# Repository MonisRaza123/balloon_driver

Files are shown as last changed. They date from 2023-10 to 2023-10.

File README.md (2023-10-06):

# balloon_driver
LED Balloon Targets is an LED based electronic version of the popular game Shooting Targets. In this game, the player has to shoot at balloon targets using the gun. The LEDs emulate the balloons and a laser gun is used to shoot them. The LED balloons are arranged in a 4 x 3 matrix.
One LED balloon is made of 4 LEDs and an LDR is embedded in the centre. So there is one LDR corresponding to each balloon. The player has to actually aim at the LDR by the laser gun to shoot the LED balloon. All LED balloons are lighted up initially. As soon as laser falls on any LDR, the LEDs of the corresponding balloon turn off. Once all the LED balloons go off, the buzzer is turned on to indicate the same.
Do you have what it takes to be a great shooter? Test your shooting skills using this game. Load the gun, press the trigger and shoot!

Let us first list down the requirements of the proposed project as follows:
- A device to sense the light coming from laser gun.
- An output device to emulate the balloon.
- An output device to indicate that the game is over.
- A microcontroller to do all the processing.
- A supply to power up the whole circuit.

Now we will try to place the above requirements in the six-box model:
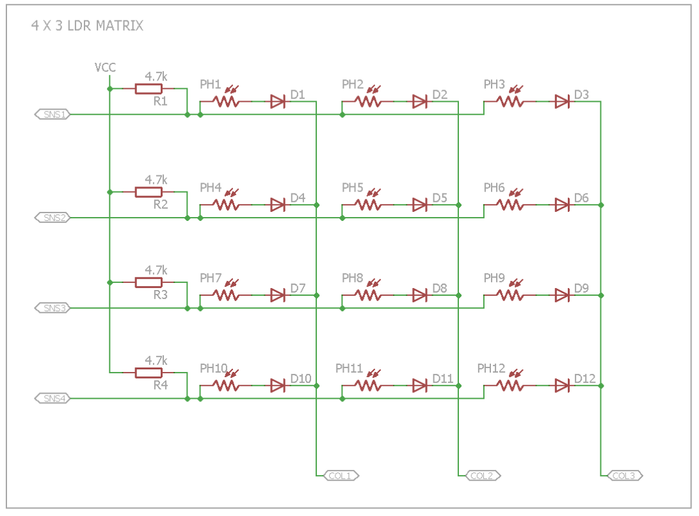
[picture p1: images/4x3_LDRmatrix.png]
1. INPUT: LDR (light-dependent resistor) to detect the change in light when laser falls on it. LDRs are arranged in a 4x3 matrix. 
1. OUTPUTS:
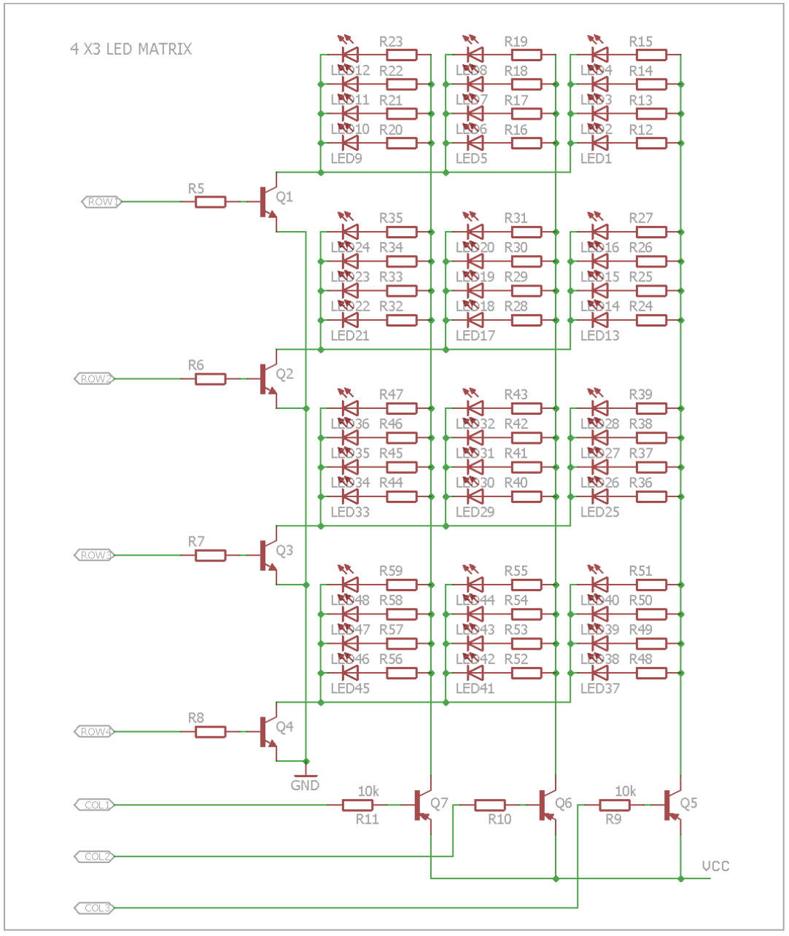
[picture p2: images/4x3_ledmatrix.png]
   1. 4 LEDs to emulate one balloon. Bal- loons are also arranged in a 4x3 matrix. 
   2. Buzzer to indicate that the game is complete i.e. all LED balloons have been shot at.
1. MICROCONTROLLER: The microcontroller used is ESP32 Wroom32.
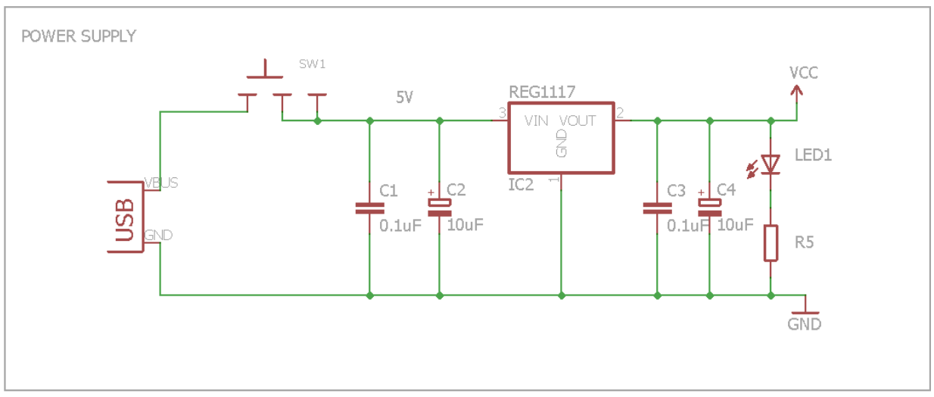
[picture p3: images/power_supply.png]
1. POWER SUPPLY: For keeping the project portable, the power is supplied through a USB Mini B connector, which brings in a raw 5V. This voltage is not suitable to be fed directly to the ESP32. Therefore, LM1117 LDO voltage regulator that gives 3.3V output is used.
1. COMMUNICATION: A 4-pin connector, with Test, Reset, Vcc and GND signals, is provided for downloading code from the emulator. This ensures that the user doesn't have to disconnect the microcontroller from the PCB repeatedly to code it.

## Block Diagram
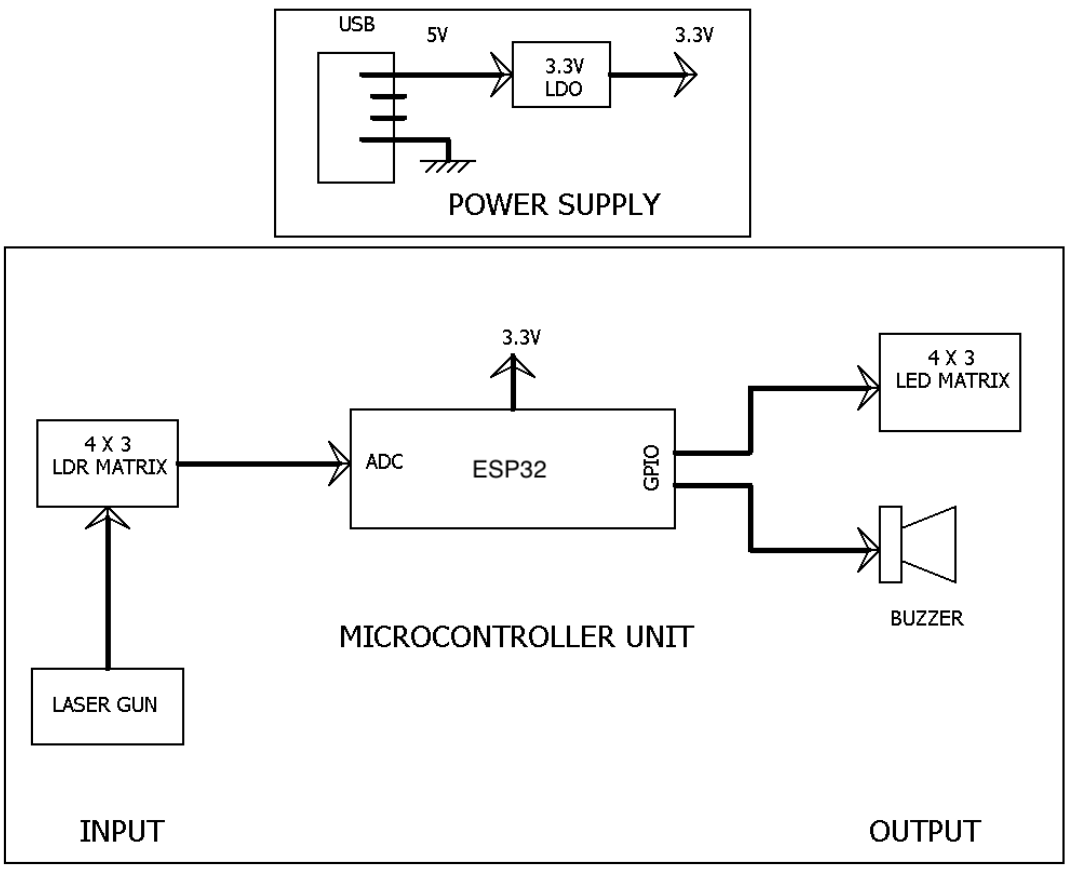
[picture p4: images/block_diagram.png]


## Hardware Description
The hardware of our project comprises of two boards: 
1. Driver circuit board - Consisting of power supply, ESP32 microcontroller, buzzer and connectors.
2. LED Balloon board - Consisting of 4 x 3 LDR matrix and 4 x 3 LED balloon matrix and connectors. The LED Balloon board is stacked above the driver circuit. For this purpose, suitable connectors have been provided.

The working of the project involves the concept of multiplexing. So, before proceeding further one must know how multiplexing works.
- Multiplexing is a technique of driving large number of LEDs using only a few pins of the microcontroller. In multiplexing a set of LEDs are lit for a brief period of time, then the next set is lit, then another set and hence the cycle repeats. This continuous switching ON and OFF of LEDs is done at a rate such that it exceeds the persistence of vision and the human eye perceives all the LEDs to be ON simultaneously.
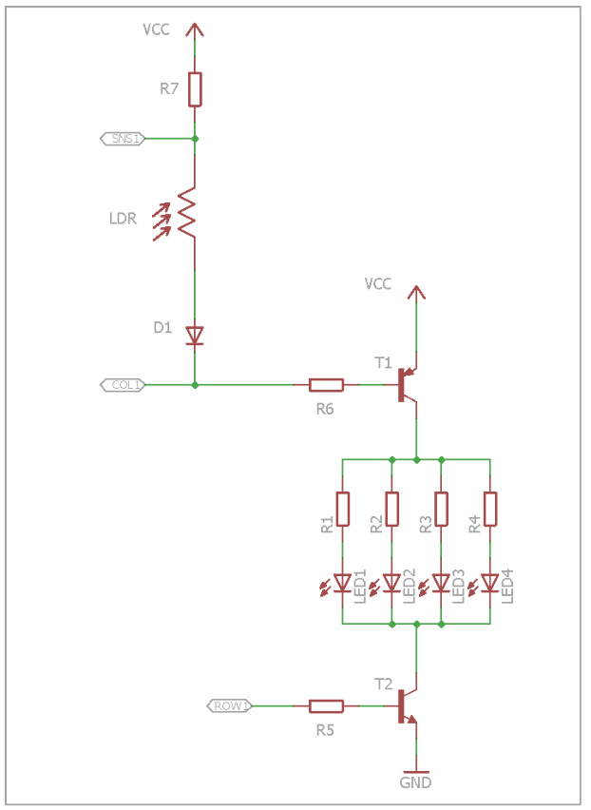
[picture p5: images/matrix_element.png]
- The 4x3 matrix consists of 12 elements. The following circuit corresponds to one element of the matrix:
- Each LED balloon is made up of 4 LEDs which are connected in parallel as shown.
- An NPN transistor, BC547, has been used for low-side switching. It provides the necessary current sinking capabilities required to drive the LEDs.
- A PNP transistor, BC557, has been used for high-side switching. It provides the necessary current sourcing capabilities required to drive the LEDs.
- The SNS1 pin reads the voltage at that point using ADC. When laser light falls on the LDR, its resistance decreases, current through it increases and voltage at SNS1 pin decreases.
- So, if the voltage value at SNS1 pin is above a certain threshold value then ROW1 pin is made high, while COL1 pin is kept low. Hence all the 4 LEDs that make up one balloon light up.
- If the voltage value at SNS1 pin is below a certain threshold value then ROW1 pin is made low, while COL1 pin is kept low. Hence all the 4 LEDs that make up one balloon turn off.
- We deal with only one column at a time. Initially, first column is activated by keeping COL1 low, COL2 and COL3 are kept high, then SNS1, SNS2, SNS3, SNS4 pins are read for the four rows and the corresponding ROW pin is made high or low accordingly. Same procedure is repeated for second and third column too.

## Flowchart
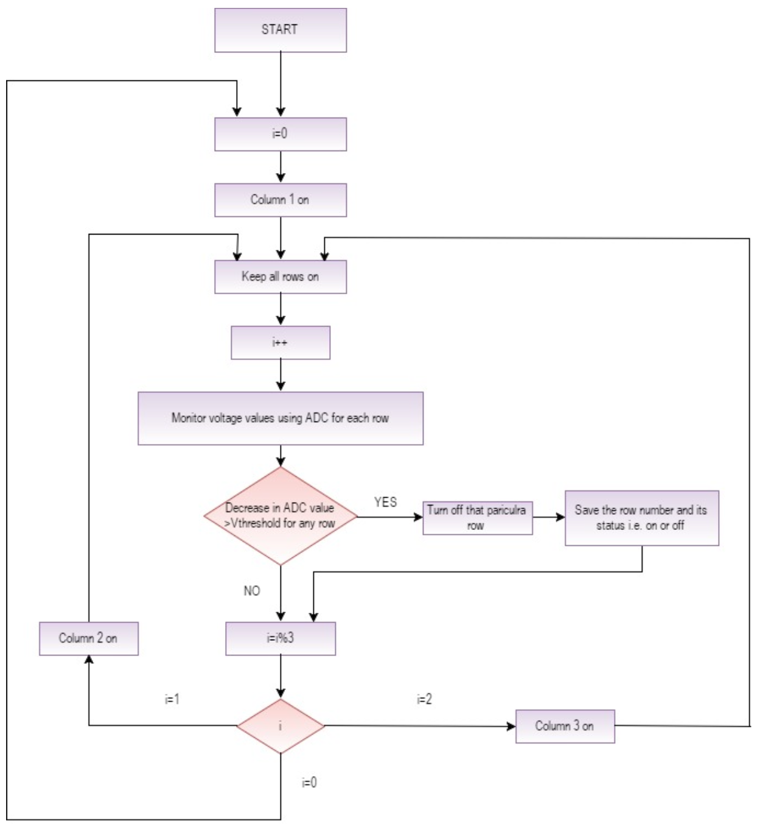
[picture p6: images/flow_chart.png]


## Circuit Design
### Driver Circuit
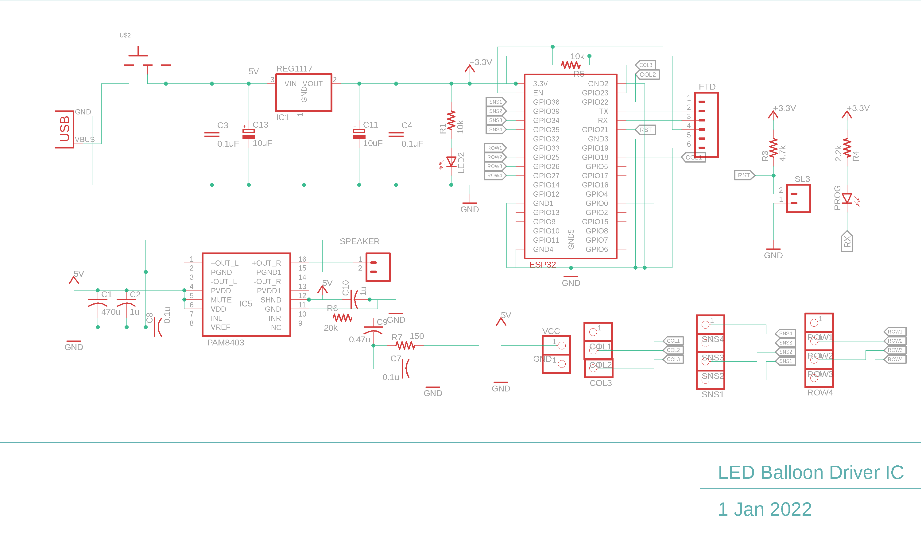
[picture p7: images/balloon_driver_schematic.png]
||
|:--:|
|*Driver board schematic*|

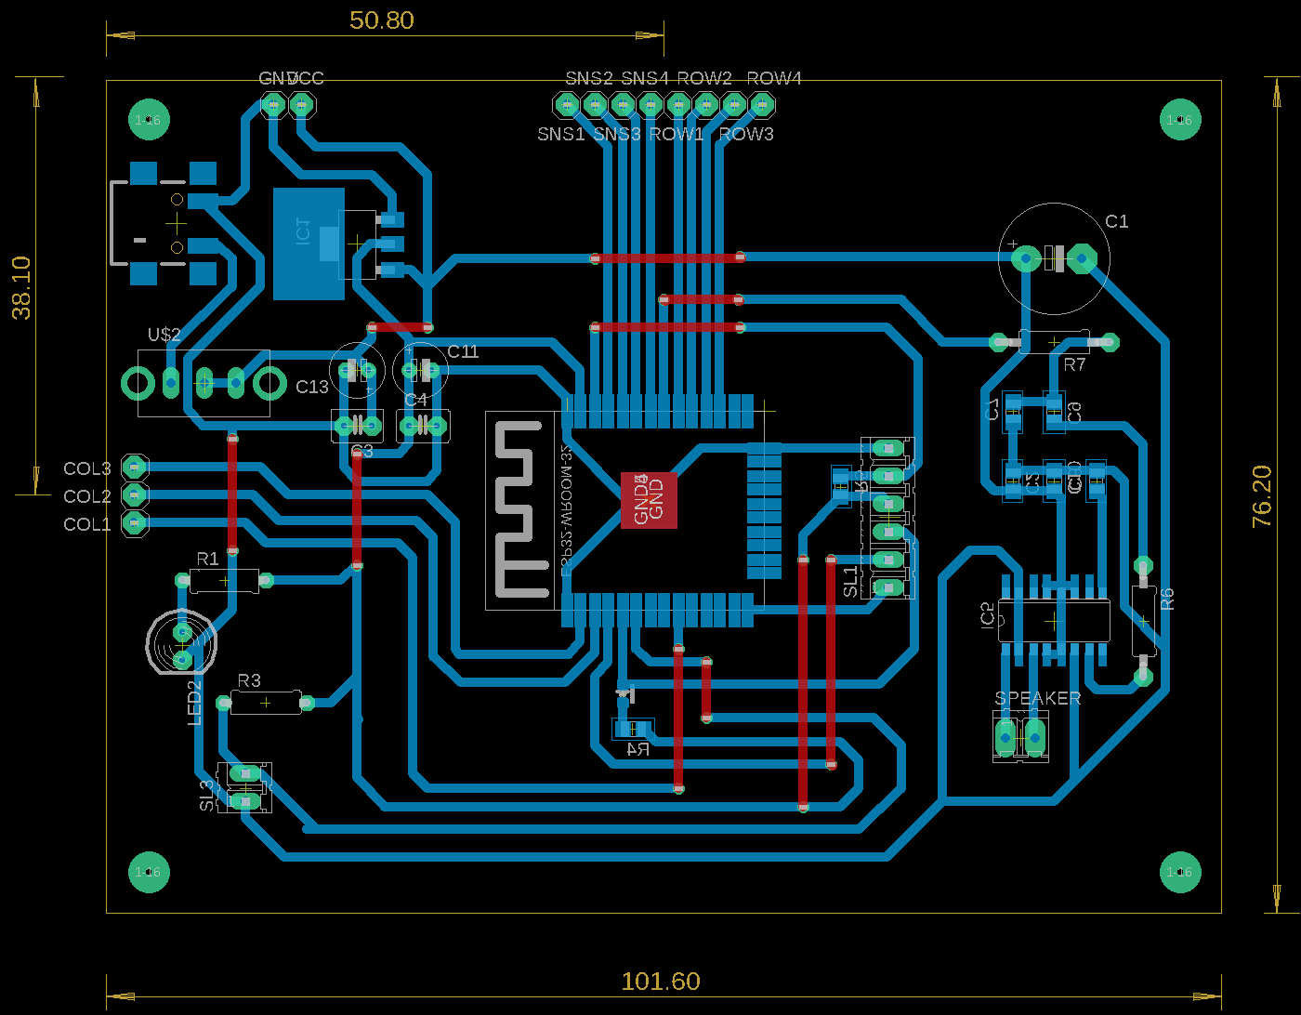
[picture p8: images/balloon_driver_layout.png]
||
|:--:|
|*Driver board layout*|

### LED Balloon Circuit
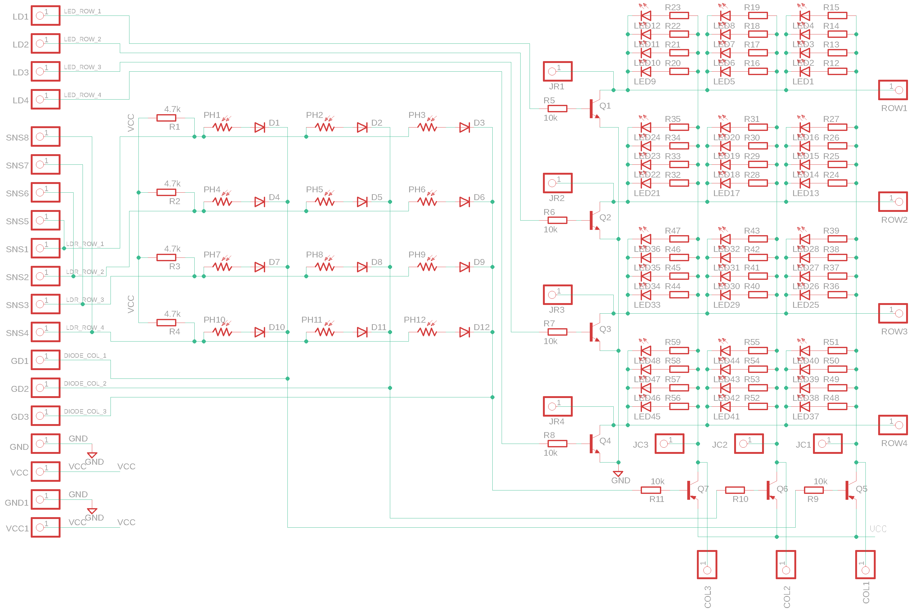
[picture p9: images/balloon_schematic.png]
||
|:--:|
|*Balloon board schematic*|

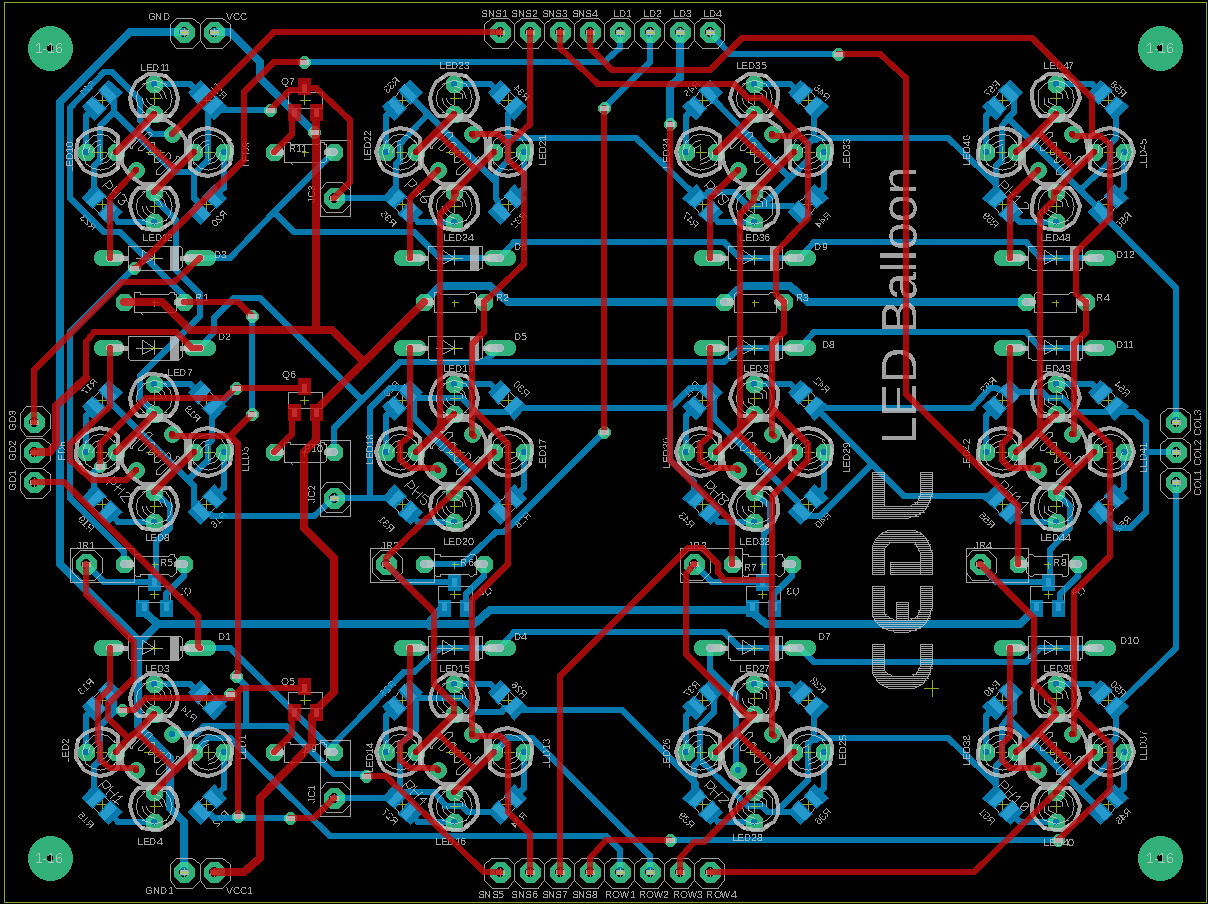
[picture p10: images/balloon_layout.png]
||
|:--:|
|*Balloon board layout*|

## Fabricated PCB
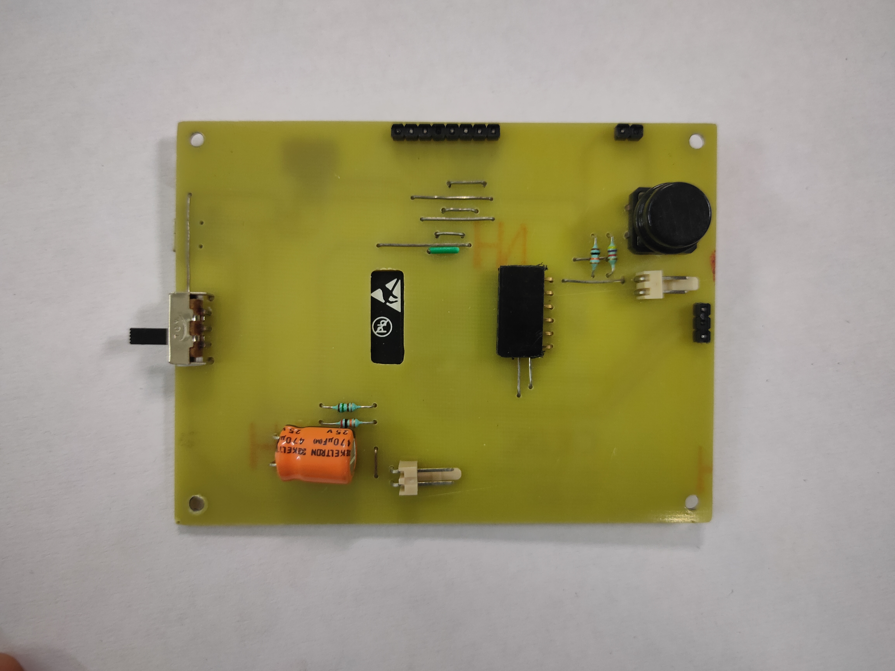
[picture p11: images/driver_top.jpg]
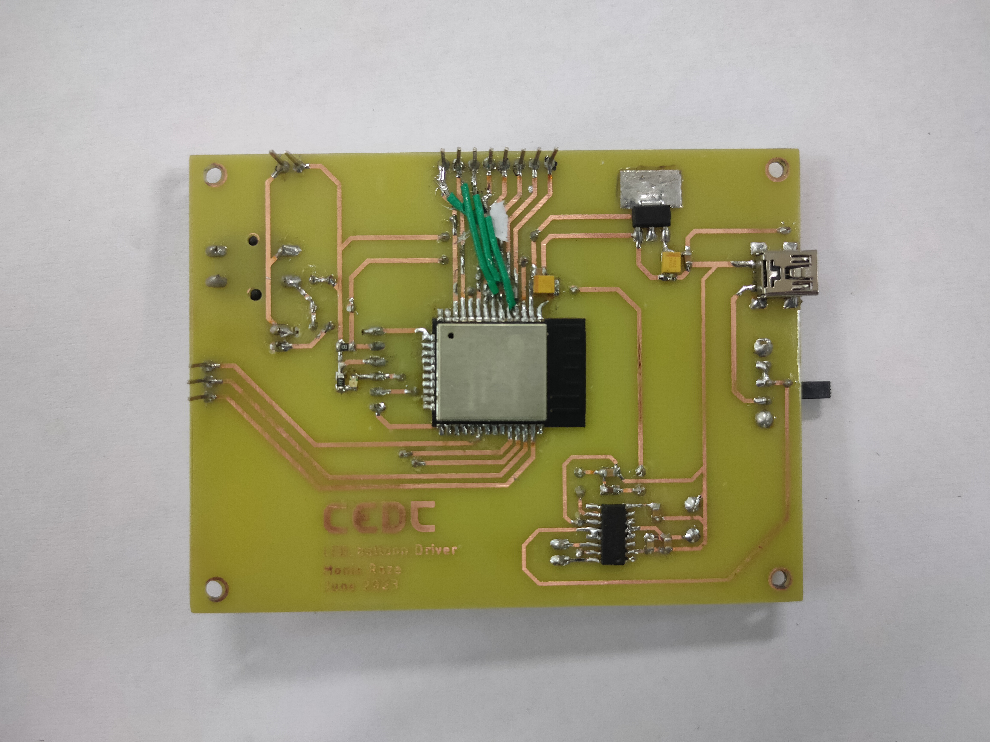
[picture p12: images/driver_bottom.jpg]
|||
|:--:|:--:|
|*Driver board(top)*|*Driver board(bottom)*|
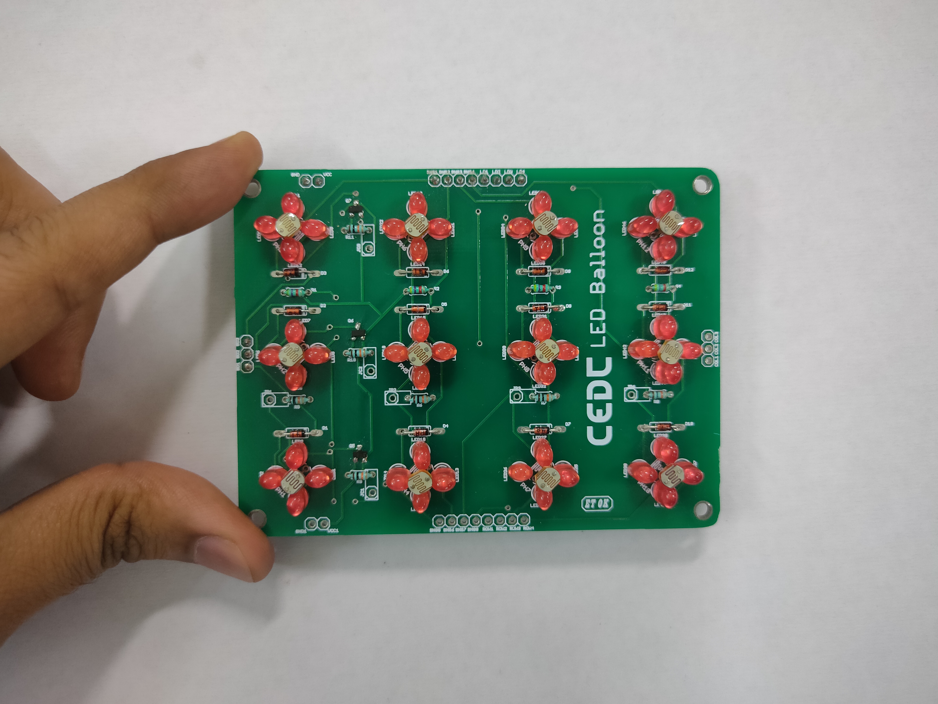
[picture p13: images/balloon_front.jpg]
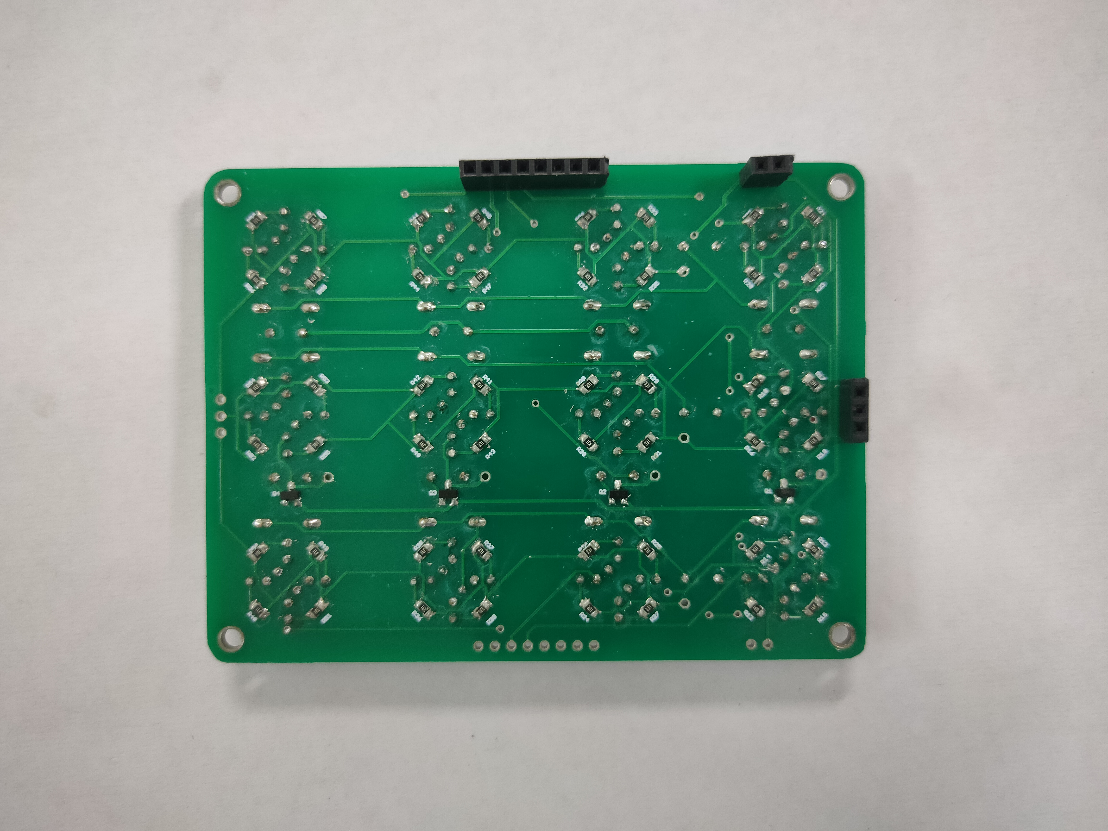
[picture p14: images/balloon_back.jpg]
|||
|*Balloon board(top)*|*Balloon board(bottom)*|

## 3D Enclosure
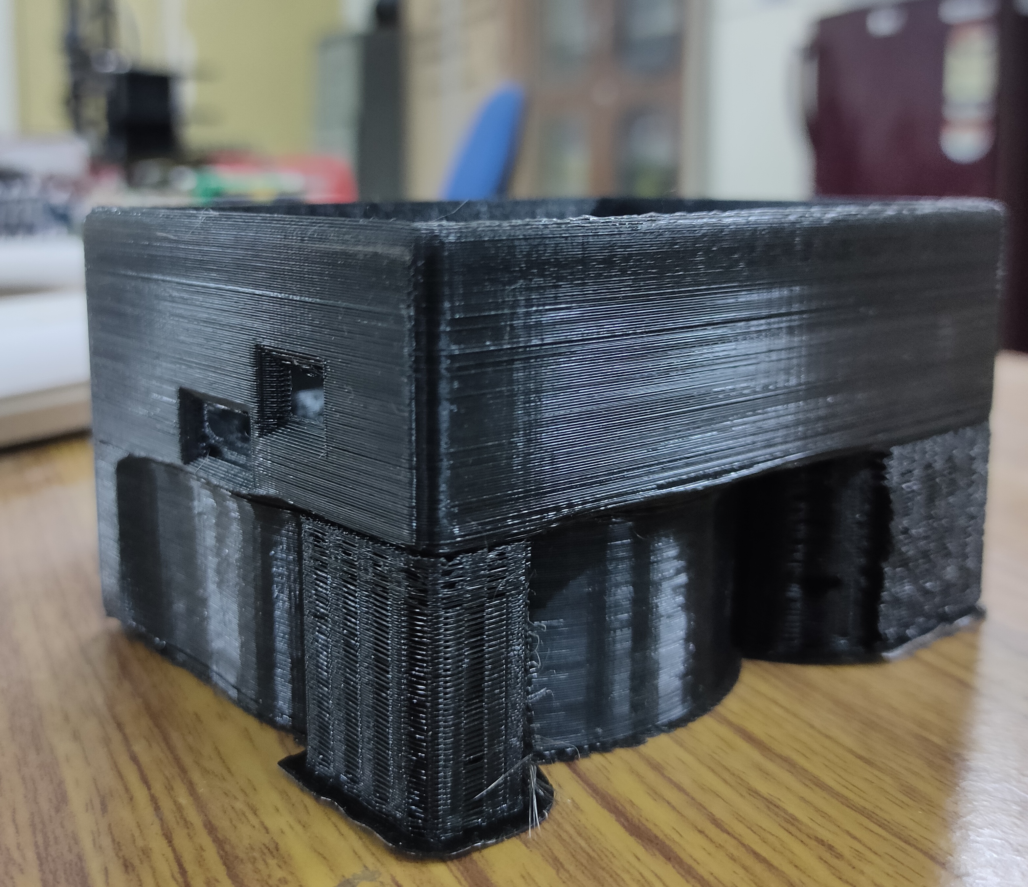
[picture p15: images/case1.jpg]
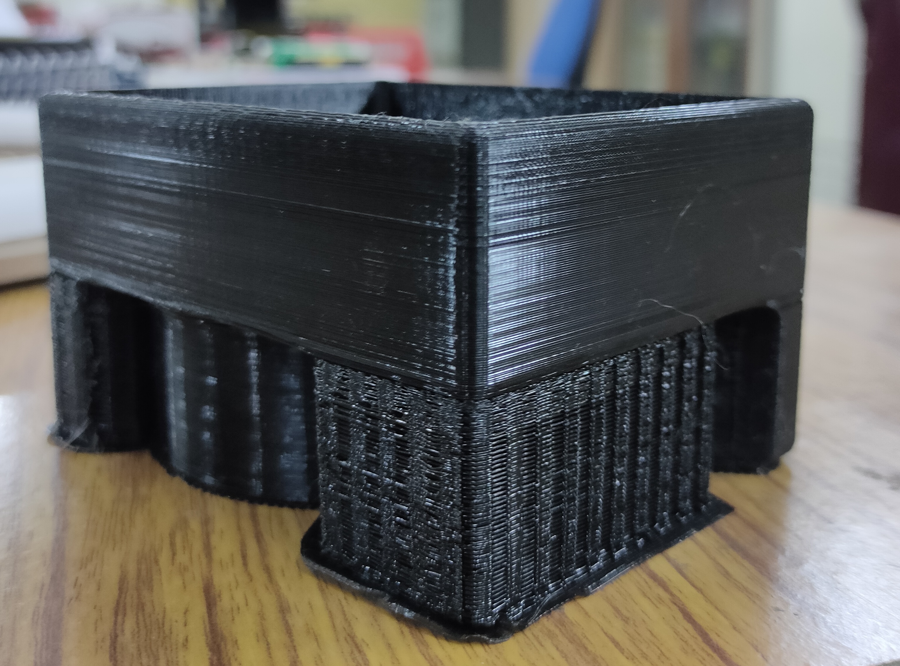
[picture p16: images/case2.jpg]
|||
|:--:|:--:|
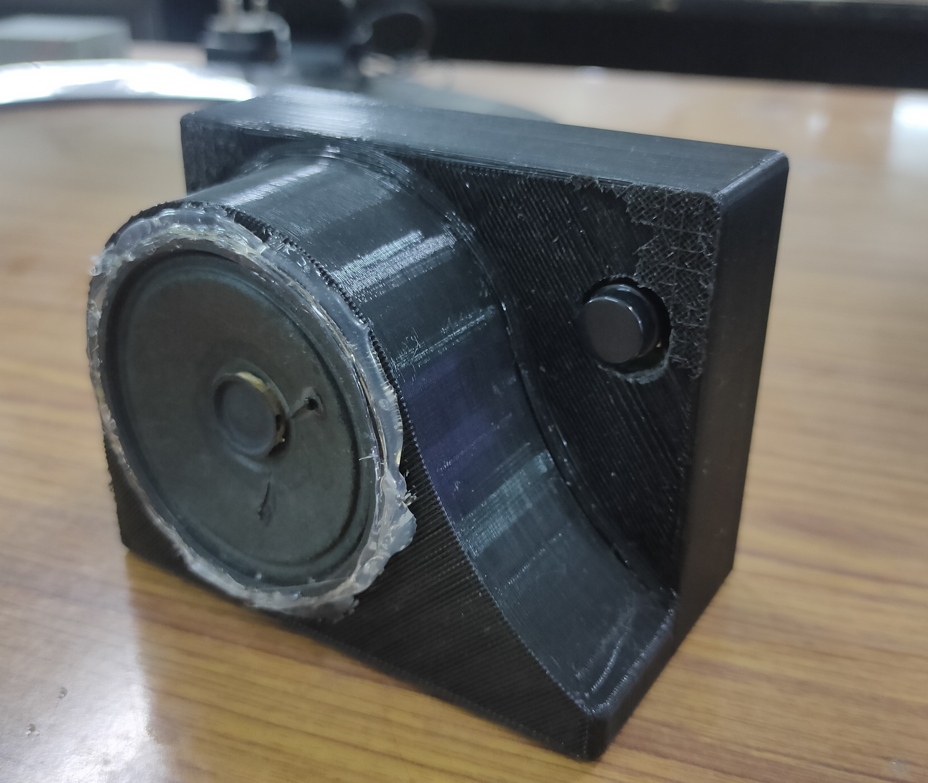
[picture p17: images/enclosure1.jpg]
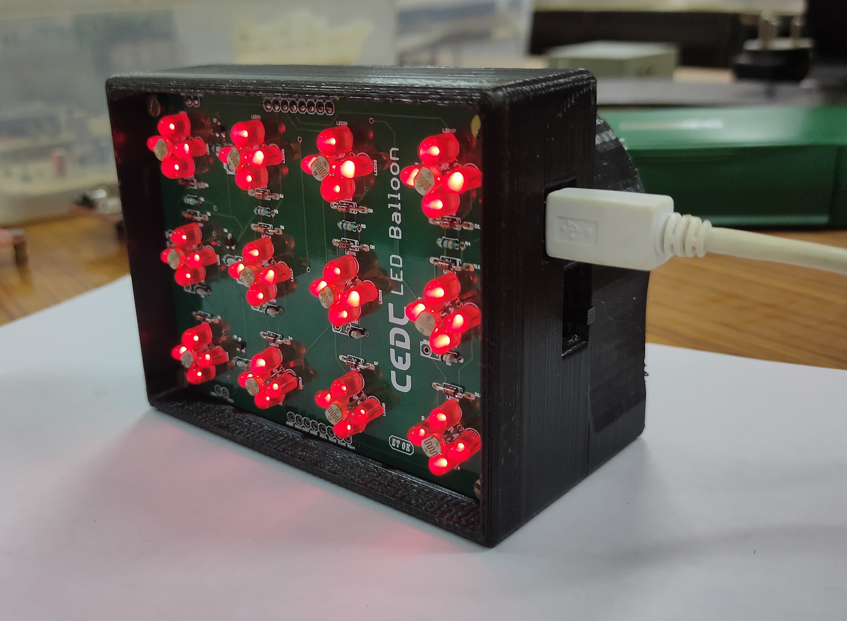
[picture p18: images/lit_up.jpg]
|||

## Working Video
Watch the video (https://youtu.be/jwfrnw1AABk)

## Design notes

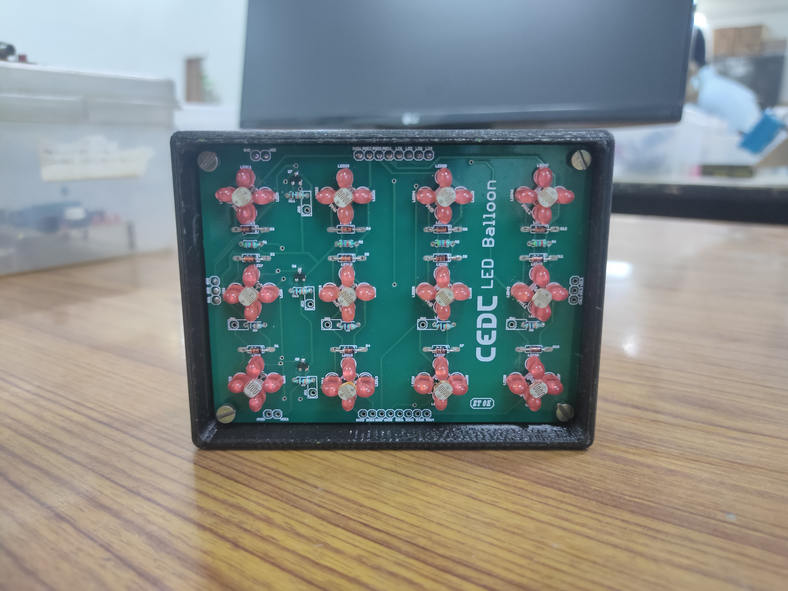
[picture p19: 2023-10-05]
images/enclosure3.jpg

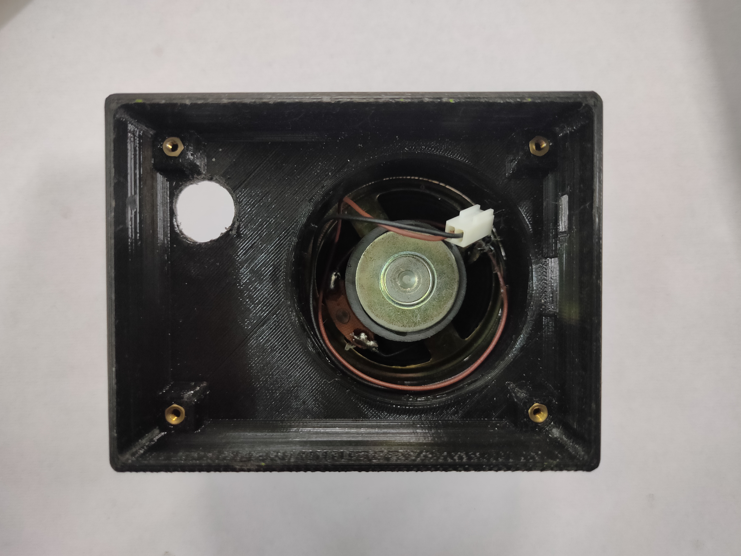
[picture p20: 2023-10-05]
images/case_internal.jpg

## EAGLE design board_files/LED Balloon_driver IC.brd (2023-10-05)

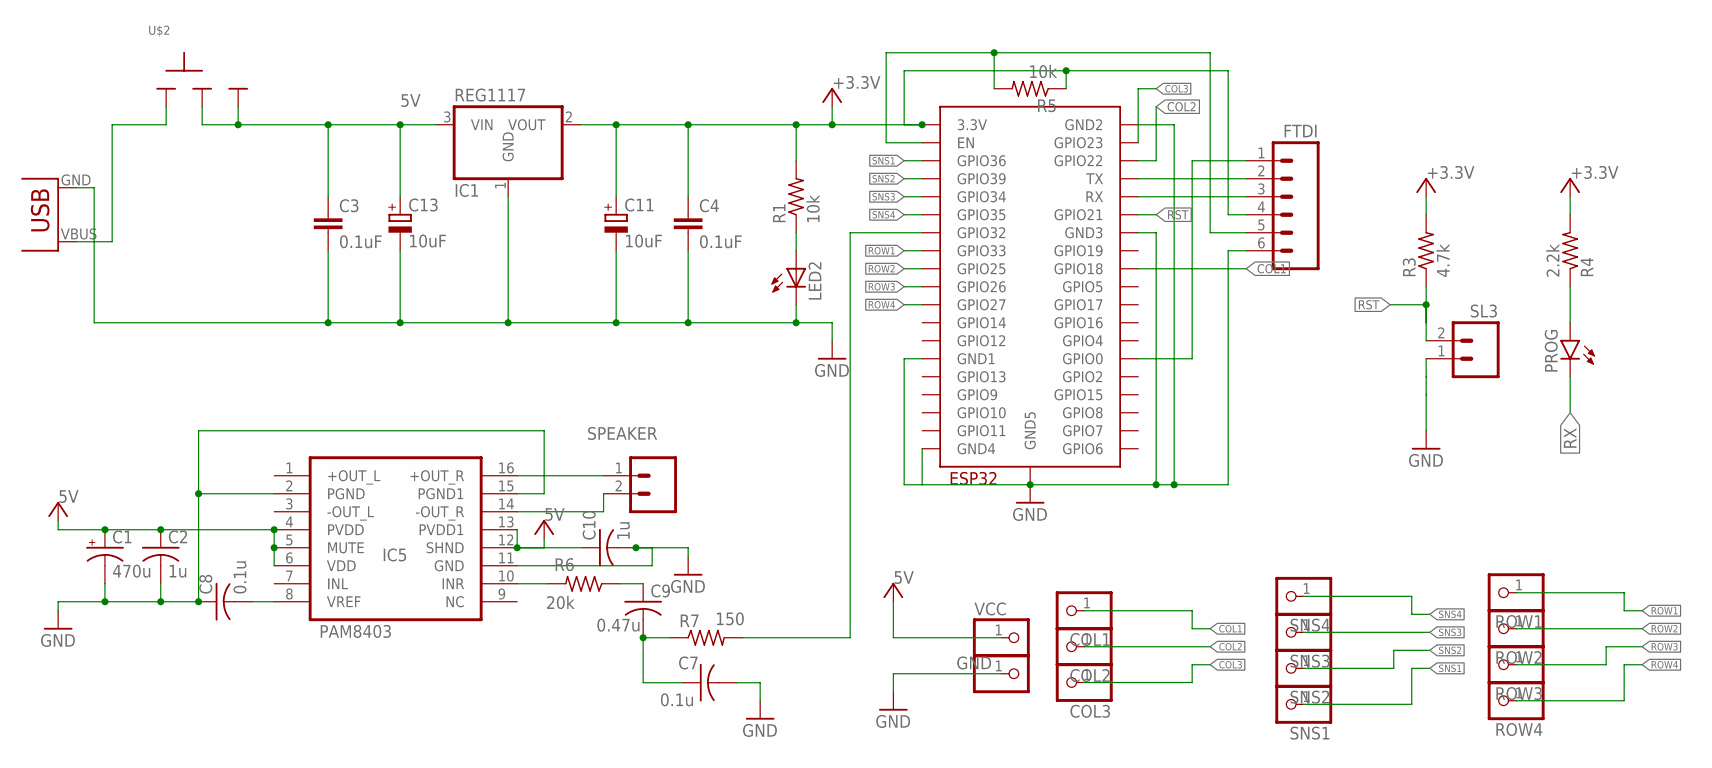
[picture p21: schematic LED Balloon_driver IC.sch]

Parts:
C1: 470u; E5-10,5
C2, C10: 1u; C0805
C3, C4: 0.1uF; C2.5-3
C7, C8: 0.1u; C0805
C9: 0.47u; C0805
C11, C13: 10uF; E2-5
COL1, COL2, COL3: PINHD-1X1; 1X01
ESP32_MODULE: ESP32-WROOM
GND: PINHD-1X1; 1X01
IC1: REG1117; SOT223
IC5: PAM8403; SOP-16
LED2: LED5MM
PROG: LED-RED0603; 0603-RED
R1: 10k; 0207/7
R3: 4.7k; 0207/7
R4: 2.2k; R0805
R5: 10k; R0805
R6: 20k; 0207/10
R7: 150; 0207/10
ROW1, ROW2, ROW3, ROW4: PINHD-1X1; 1X01
SL1: FTDI; 06P
SL3: M02; 02P
SNS1, SNS2, SNS3, SNS4: PINHD-1X1; 1X01
SPEAKER: M02; 02P
U$1: USB(POWER)
U$2: SLIDESWITCH-BIG; BIGSWITCH
VCC: PINHD-1X1; 1X01

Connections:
5V: C1.+, C2.1, C3.1, C10.1, C13.+, IC1.3 (VIN), IC5.4 (PVDD), IC5.5 (MUTE), IC5.6 (VDD), IC5.12 (SHND), IC5.13 (PVDD1), U$2.2, U$2.3, VCC.1
+3.3V: C4.1, C11.+, ESP32_MODULE.3V3 (3.3V), IC1.2 (VOUT), R1.2, R3.2, R4.2, R5.1, SL1.4
COL1: COL1.1, ESP32_MODULE.IO18 (GPIO18)
COL2: COL2.1, ESP32_MODULE.IO22 (GPIO22)
COL3: COL3.1, ESP32_MODULE.IO23 (GPIO23)
EN: ESP32_MODULE.EN, R5.2, SL1.5
GND: C1.-, C2.2, C3.2, C4.2, C7.2, C8.1, C10.2, C11.-, C13.-, ESP32_MODULE.GND1, ESP32_MODULE.GND2, ESP32_MODULE.GND3, ESP32_MODULE.GND4, ESP32_MODULE.GND5, GND.1, IC1.1 (GND), IC5.2 (PGND), IC5.11 (GND), IC5.15 (PGND1), LED2.K (C), SL1.6, SL3.1, U$1.GND
unnamed: IC5.16 (+OUT_R), SPEAKER.1
unnamed: IC5.10 (INR), R6.2
unnamed: C8.2, IC5.8 (VREF)
unnamed: PROG.A, R4.1
unnamed: C9.1, R6.1
unnamed: ESP32_MODULE.IO0 (GPIO0), SL1.1
unnamed: IC5.14 (-OUT_R), SPEAKER.2
unnamed: LED2.A, R1.1
unnamed: C7.1, C9.2, R7.1
unnamed: U$1.VBUS (VCC), U$2.1
PWM: ESP32_MODULE.IO32 (GPIO32), R7.2
ROW1: ESP32_MODULE.IO33 (GPIO33), ROW1.1
ROW2: ESP32_MODULE.IO25 (GPIO25), ROW2.1
ROW3: ESP32_MODULE.IO26 (GPIO26), ROW3.1
ROW4: ESP32_MODULE.IO27 (GPIO27), ROW4.1
RST: ESP32_MODULE.IO21 (GPIO21), R3.1, SL3.2
RX: ESP32_MODULE.RX, PROG.C, SL1.3
SNS1: ESP32_MODULE.SENSOR_VP (GPIO36), SNS1.1
SNS2: ESP32_MODULE.SENSOR_VN (GPIO39), SNS2.1
SNS3: ESP32_MODULE.IO34 (GPIO34), SNS3.1
SNS4: ESP32_MODULE.IO35 (GPIO35), SNS4.1
TX: ESP32_MODULE.TX, SL1.2

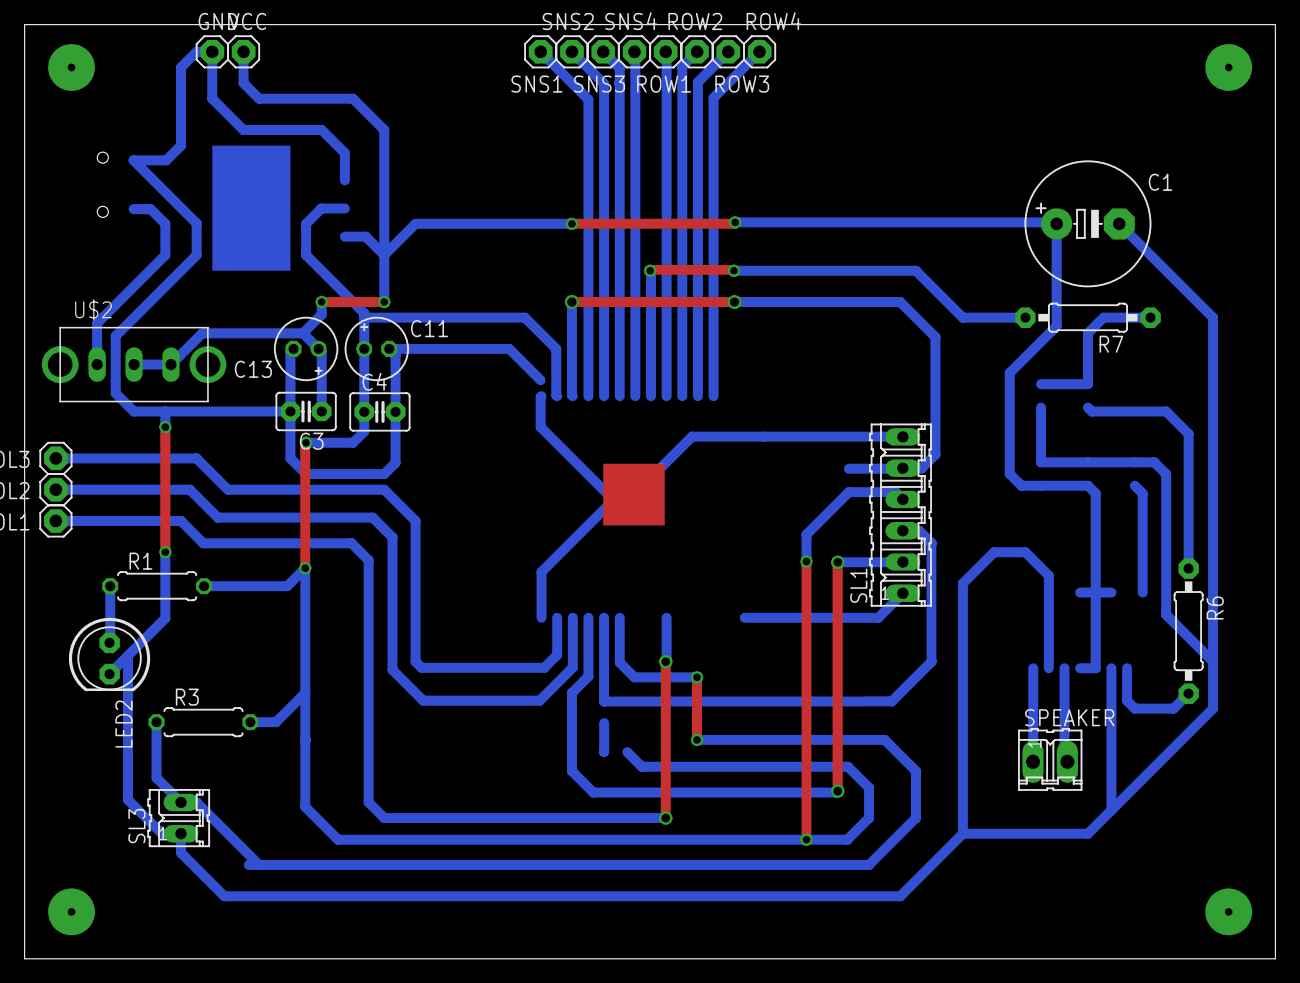
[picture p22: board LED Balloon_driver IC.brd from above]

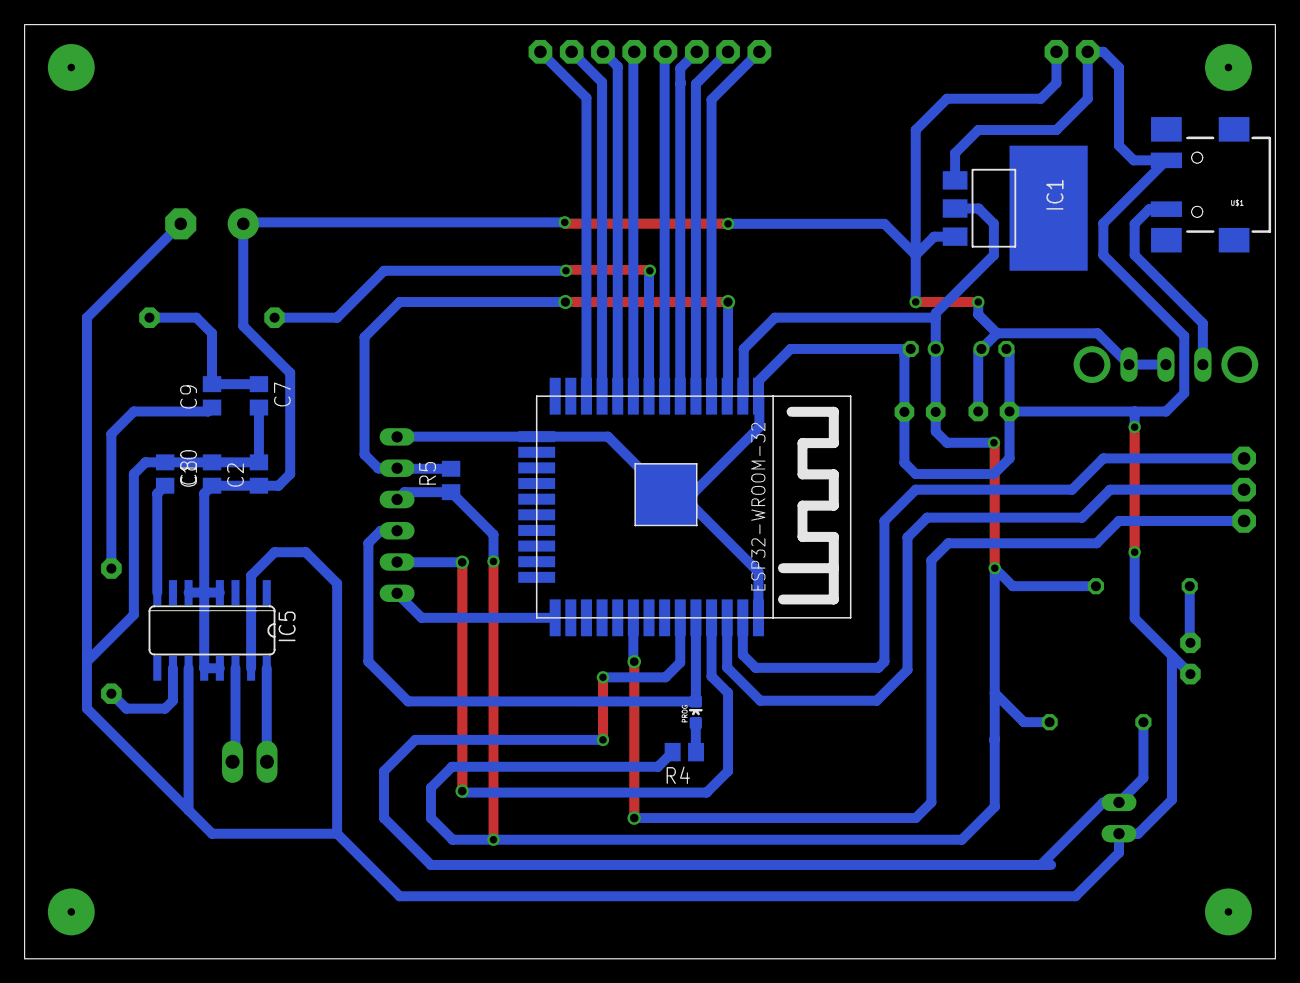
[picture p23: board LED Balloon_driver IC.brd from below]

Board: 2 copper layers, 101.6 x 75.9 mm, 39 parts (12 on the bottom side), 29 nets.

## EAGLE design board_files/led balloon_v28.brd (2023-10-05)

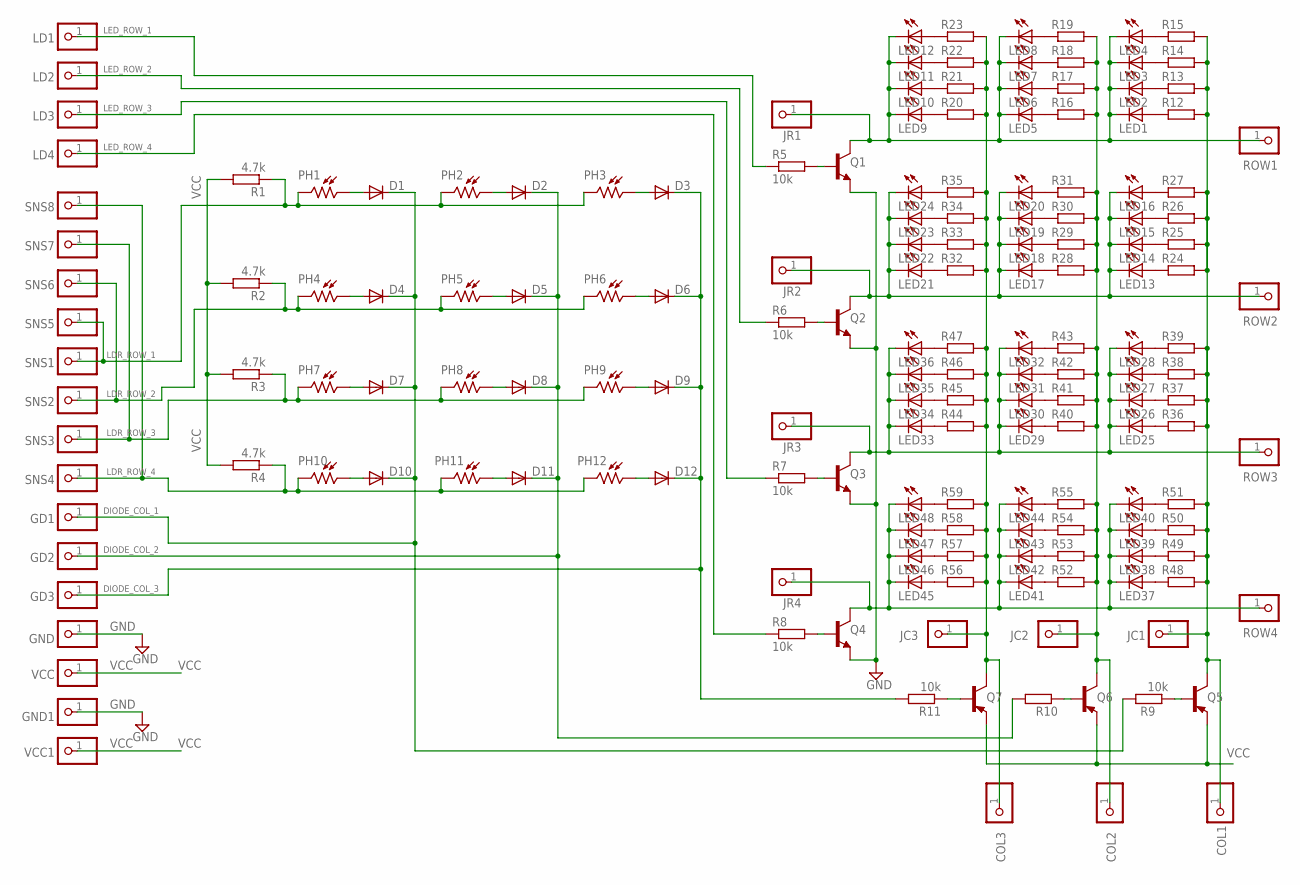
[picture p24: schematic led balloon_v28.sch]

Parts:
COL1, COL2, COL3: PINHD-1X1; 1X01
D1, D2, D3, D4, D5, D6, D7, D8, D9, D10, D11, D12: 1N4148DO35-7; DO35-7
GD1, GD2, GD3: PINHD-1X1; 1X01
GND, GND1: PINHD-1X1; 1X01
JC1, JC2, JC3: PINHD-1X1; 1X01
JR1, JR2, JR3, JR4: PINHD-1X1; 1X01
LD1, LD2, LD3, LD4: PINHD-1X1; 1X01
LED1, LED2, LED3, LED4, LED5, LED6, LED7, LED8, LED9, LED10, LED11, LED12, LED13, LED14, LED15, LED16, LED17, LED18, LED19, LED20, LED21, LED22, LED23, LED24, LED25, LED26, LED27, LED28, LED29, LED30, LED31, LED32, LED33, LED34, LED35, LED36, LED37, LED38, LED39, LED40, LED41, LED42, LED43, LED44, LED45, LED46, LED47, LED48: LED3MM
PH1: LDR; VT900
PH2, PH3, PH4, PH5, PH6, PH7, PH8, PH9, PH10, PH11, PH12: VT83N4; VT800
Q1, Q2, Q3, Q4: BC847ASMD; SOT23
Q5, Q6, Q7: BC807-40SMD; SOT23-BEC
R1, R2, R3, R4: 4.7k; 0204/5
R5, R6, R7, R8, R9, R10, R11: 10k; 0204/5
R12, R13, R14, R15, R16, R17, R18, R19, R20, R21, R22, R23, R24, R25, R26, R27, R28, R29, R30, R31, R32, R33, R34, R35, R36, R37, R38, R39, R40, R41, R42, R43, R44, R45, R46, R47, R48, R49, R50, R51, R52, R53, R54, R55, R56, R57, R58, R59: R-EU_R0805; R0805
ROW1, ROW2, ROW3, ROW4: PINHD-1X1; 1X01
SNS1, SNS2, SNS3, SNS4, SNS5, SNS6, SNS7, SNS8: PINHD-1X1; 1X01
VCC, VCC1: PINHD-1X1; 1X01

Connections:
DIODE_COL_1: D1.C, D4.C, D7.C, D10.C, GD1.1, R9.2
DIODE_COL_2: D2.C, D5.C, D8.C, D11.C, GD2.1, R10.2
DIODE_COL_3: D3.C, D6.C, D9.C, D12.C, GD3.1, R11.2
GND: GND.1, GND1.1, Q1.2 (E), Q2.2 (E), Q3.2 (E), Q4.2 (E)
LDR_ROW_1: PH1.2, PH2.2, PH3.2, R1.1, SNS1.1, SNS5.1
LDR_ROW_2: PH4.2, PH5.2, PH6.2, R2.1, SNS2.1, SNS6.1
LDR_ROW_3: PH7.2, PH8.2, PH9.2, R3.1, SNS3.1, SNS7.1
LDR_ROW_4: PH10.2, PH11.2, PH12.2, R4.1, SNS4.1, SNS8.1
LED_ROW_1: LD1.1, R5.1
LED_ROW_2: LD2.1, R6.1
LED_ROW_3: LD3.1, R7.1
LED_ROW_4: LD4.1, R8.1
unnamed: D1.A, PH1.1
unnamed: D2.A, PH2.1
unnamed: D3.A, PH3.1
unnamed: D6.A, PH6.1
unnamed: D5.A, PH5.1
unnamed: D4.A, PH4.1
unnamed: D7.A, PH7.1
unnamed: D8.A, PH8.1
unnamed: D9.A, PH9.1
unnamed: D12.A, PH12.1
unnamed: D11.A, PH11.1
unnamed: D10.A, PH10.1
unnamed: Q6.B, R10.1
unnamed: Q7.B, R11.1
unnamed: Q5.B, R9.1
unnamed: JR1.1, LED1.K (C), LED2.K (C), LED3.K (C), LED4.K (C), LED5.K (C), LED6.K (C), LED7.K (C), LED8.K (C), LED9.K (C), LED10.K (C), LED11.K (C), LED12.K (C), Q1.3 (C), ROW1.1
unnamed: LED1.A, R12.1
unnamed: LED2.A, R13.1
unnamed: LED3.A, R14.1
unnamed: LED4.A, R15.1
unnamed: Q1.1 (B), R5.2
unnamed: JR3.1, LED25.K (C), LED26.K (C), LED27.K (C), LED28.K (C), LED29.K (C), LED30.K (C), LED31.K (C), LED32.K (C), LED33.K (C), LED34.K (C), LED35.K (C), LED36.K (C), Q3.3 (C), ROW3.1
unnamed: LED9.A, R20.1
unnamed: LED10.A, R21.1
unnamed: LED11.A, R22.1
unnamed: COL2.1, JC2.1, Q6.C, R16.2, R17.2, R18.2, R19.2, R28.2, R29.2, R30.2, R31.2, R40.2, R41.2, R42.2, R43.2, R52.2, R53.2, R54.2, R55.2
unnamed: LED13.A, R24.1
unnamed: Q2.1 (B), R6.2
unnamed: LED5.A, R16.1
unnamed: LED6.A, R17.1
unnamed: LED7.A, R18.1
unnamed: LED8.A, R19.1
unnamed: LED14.A, R25.1
unnamed: Q3.1 (B), R7.2
unnamed: LED12.A, R23.1
unnamed: LED15.A, R26.1
unnamed: LED16.A, R27.1
unnamed: LED17.A, R28.1
unnamed: Q4.1 (B), R8.2
unnamed: LED18.A, R29.1
unnamed: LED19.A, R30.1
unnamed: LED20.A, R31.1
unnamed: COL1.1, JC1.1, Q5.C, R12.2, R13.2, R14.2, R15.2, R24.2, R25.2, R26.2, R27.2, R36.2, R37.2, R38.2, R39.2, R48.2, R49.2, R50.2, R51.2
unnamed: LED21.A, R32.1
unnamed: LED22.A, R33.1
unnamed: LED23.A, R34.1
unnamed: LED24.A, R35.1
unnamed: COL3.1, JC3.1, Q7.C, R20.2, R21.2, R22.2, R23.2, R32.2, R33.2, R34.2, R35.2, R44.2, R45.2, R46.2, R47.2, R56.2, R57.2, R58.2, R59.2
unnamed: LED25.A, R36.1
unnamed: LED26.A, R37.1
unnamed: LED27.A, R38.1
unnamed: LED28.A, R39.1
unnamed: LED29.A, R40.1
unnamed: LED30.A, R41.1
unnamed: LED31.A, R42.1
unnamed: LED32.A, R43.1
unnamed: LED33.A, R44.1
unnamed: LED34.A, R45.1
unnamed: LED35.A, R46.1
unnamed: LED36.A, R47.1
unnamed: LED37.A, R48.1
unnamed: LED38.A, R49.1
unnamed: LED39.A, R50.1
unnamed: LED40.A, R51.1
unnamed: LED41.A, R52.1
unnamed: LED42.A, R53.1
unnamed: LED43.A, R54.1
unnamed: LED44.A, R55.1
unnamed: JR2.1, LED13.K (C), LED14.K (C), LED15.K (C), LED16.K (C), LED17.K (C), LED18.K (C), LED19.K (C), LED20.K (C), LED21.K (C), LED22.K (C), LED23.K (C), LED24.K (C), Q2.3 (C), ROW2.1
unnamed: LED45.A, R56.1
unnamed: LED46.A, R57.1
unnamed: LED47.A, R58.1
unnamed: LED48.A, R59.1
unnamed: JR4.1, LED37.K (C), LED38.K (C), LED39.K (C), LED40.K (C), LED41.K (C), LED42.K (C), LED43.K (C), LED44.K (C), LED45.K (C), LED46.K (C), LED47.K (C), LED48.K (C), Q4.3 (C), ROW4.1
VCC: Q5.E, Q6.E, Q7.E, R1.2, R2.2, R3.2, R4.2, VCC.1, VCC1.1

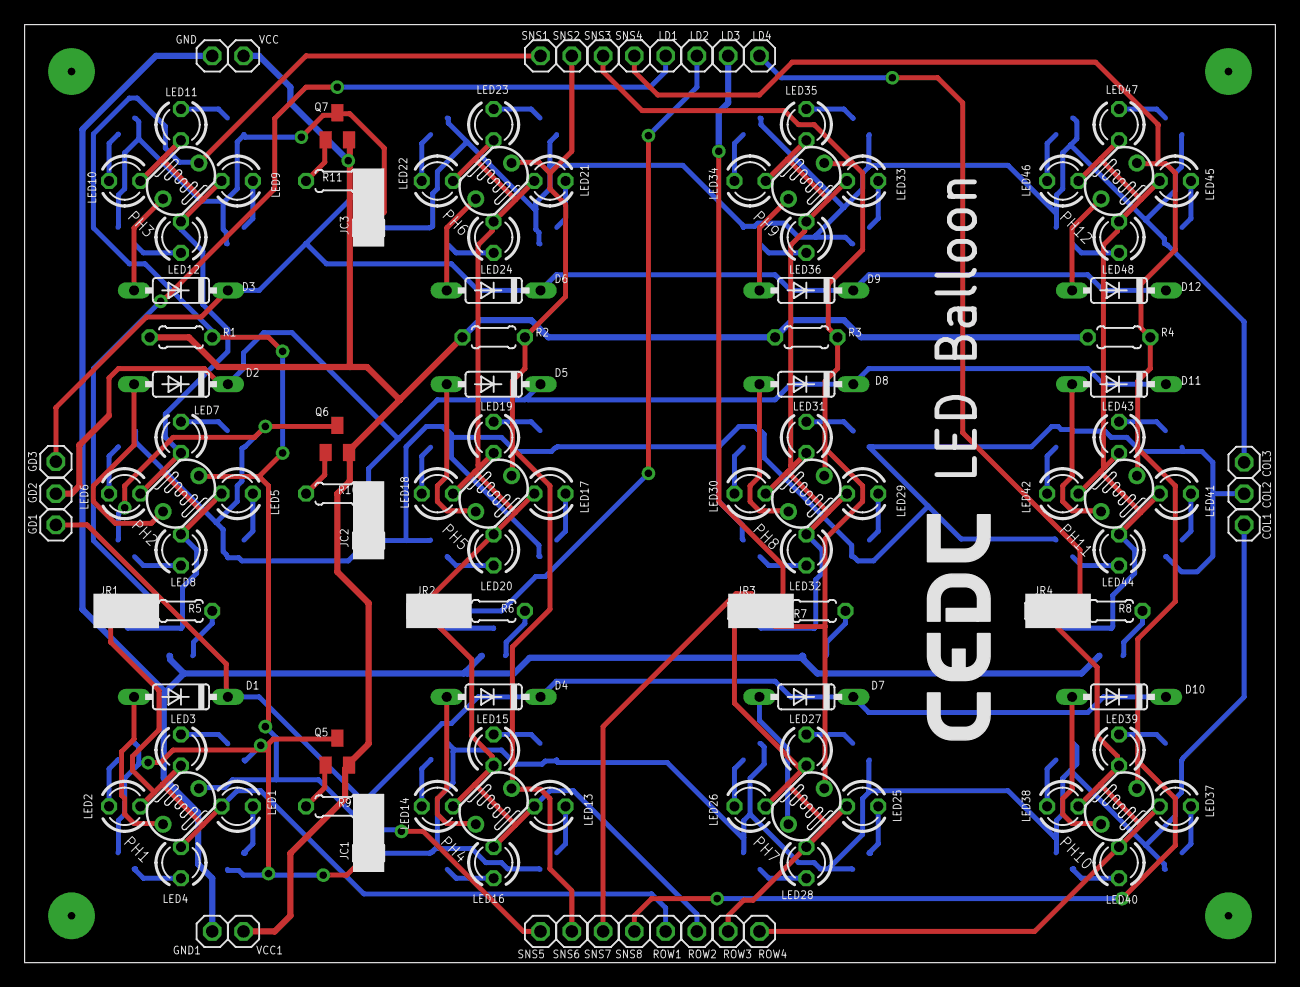
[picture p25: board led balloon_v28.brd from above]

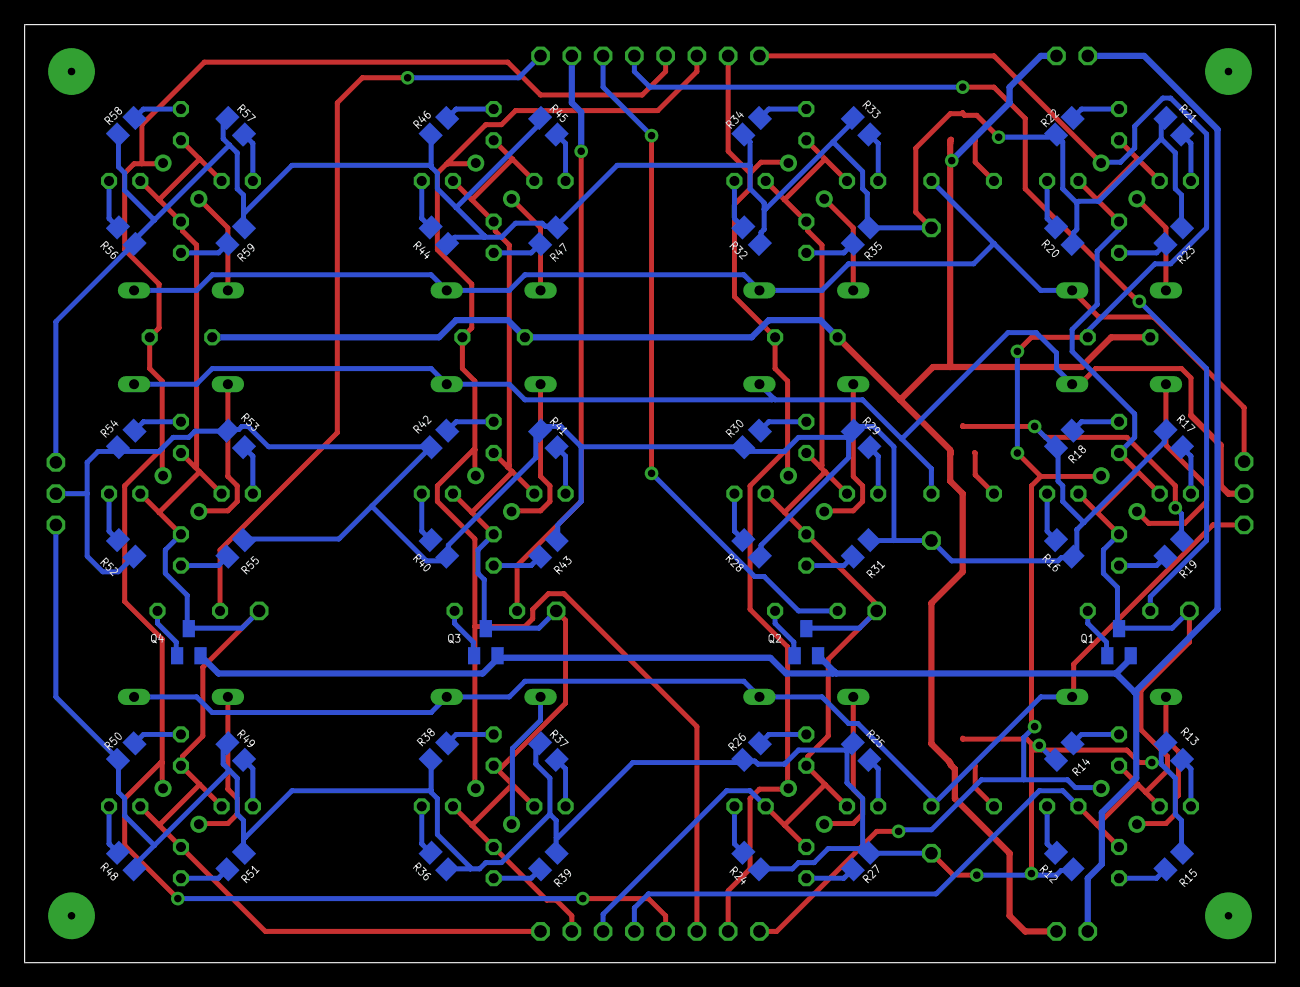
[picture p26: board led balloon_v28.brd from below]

Board: 2 copper layers, 101.6 x 76.2 mm, 172 parts (52 on the bottom side), 87 nets.

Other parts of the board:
E$1: LOGO-CEDT-SILK-18MM

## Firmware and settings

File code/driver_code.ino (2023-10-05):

// Playing a digital WAV recording repeatadly using the XTronical DAC Audio library
// prints out to the serial monitor numbers counting up showing that the sound plays 
// independently of the main loop
// See www.xtronical.com for write ups on sound, the hardware required and how to make
// the wav files and include them in your code

#include "SoundData.h"
#include "XT_DAC_Audio.h"

#define SNS1 27
#define SNS2 26
#define SNS3 33
#define SNS4 32
#define LD1 35
#define LD2 34
#define LD3 39
#define LD4 36
#define GD1 23
#define GD2 22
#define GD3 18
#define THRESH 0

XT_Wav_Class* balloons[] = {new XT_Wav_Class(b1), new XT_Wav_Class(b2), new XT_Wav_Class(b3), new XT_Wav_Class(b4),
                           new XT_Wav_Class(b5), new XT_Wav_Class(b6), new XT_Wav_Class(b7), new XT_Wav_Class(b8)};

//XT_Wav_Class balloon(b1);
                                      
XT_DAC_Audio_Class DacAudio(25,3);    // Create the main player class object. 
                                      // Use GPIO 25, one of the 2 DAC pins and timer 0

int led_state[4][3];

int sensors[] = {SNS1, SNS2, SNS3, SNS4};
int leds[] = {LD1, LD2, LD3, LD4};
int grounds[] = {GD1, GD2, GD3};

//int pwm_channel = 5;
//int pwm_freq = 40000000;

void setup() {
  Serial.begin(115200);               // Not needed for sound, just to demo printing to the serial
                                      // Monitor whilst the sound plays, ensure your serial monitor
                                      // speed is set to this speed also.
//  ledcSetup(pwm_channel, pwm_freq, 8);
//  ledcAttachPin(32, pwm_channel);

  pinMode(SNS1, INPUT);
  pinMode(SNS2, INPUT);
  pinMode(SNS3, INPUT);
  pinMode(SNS4, INPUT);
  pinMode(LD1, OUTPUT);
  pinMode(LD2, OUTPUT);
  pinMode(LD3, OUTPUT);
  pinMode(LD4, OUTPUT);
  pinMode(GD1, OUTPUT);
  pinMode(GD2, OUTPUT);
  pinMode(GD3, OUTPUT);

  for(int i=0; i<4; i++){
    for(int j=0; j<3; j++){
      led_state[i][j] = HIGH;
    }
  }
}

int sound_counter = 0;
bool play = false;

void loop() {
  DacAudio.FillBuffer();                // Fill the sound buffer with data
  if(play){
    DacAudio.Play(balloons[sound_counter]);
    play = false;
  }
  
  for(int j=0; j<3; j++){
    digitalWrite(grounds[j], LOW);
    digitalWrite(grounds[(j+1)%3], HIGH);
    digitalWrite(grounds[(j+2)%3], HIGH);
    for(int i=0; i<4; i++){
      digitalWrite(leds[i], led_state[i][j]);
      delay(1);
      digitalWrite(leds[i], LOW);

      if(analogRead(sensors[i]) < THRESH && led_state[i][j] == HIGH){

        sound_counter = (sound_counter + 1)%8;
        
        led_state[i][j] = LOW;

        play = true;
      }

      if(i == 0 && j == 2){
        Serial.print(j);
        Serial.print(" ");
        Serial.print(i);
        Serial.print(" ");
        Serial.println(analogRead(sensors[i]));
      }
    }
  }
}
